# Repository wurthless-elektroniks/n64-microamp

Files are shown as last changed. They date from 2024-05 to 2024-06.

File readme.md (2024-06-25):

# n64-microamp: Extremely cheap and janky Nintendo 64 RGB amp mod

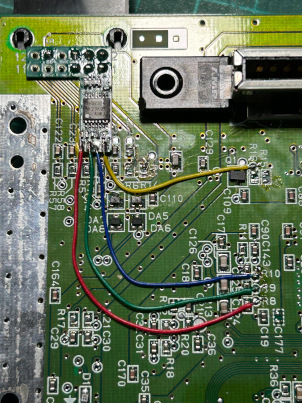
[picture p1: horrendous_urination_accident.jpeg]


Another exercise in extreme cost-downing. This time, it's an attempt to make the most minimalist yet still functional Nintendo 64 RGB amp.
This is accomplished in only eight tiny annoying-to-solder parts.

Circuit is entirely analog so you only get the Gerbers.

## Schematic

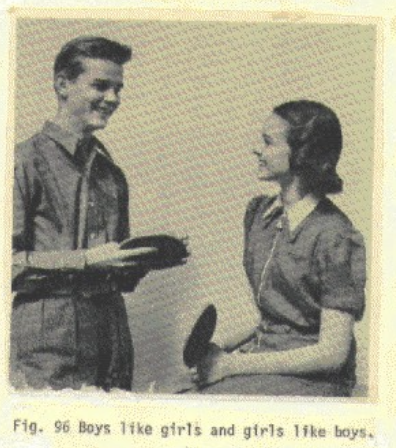
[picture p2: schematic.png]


Virtually the same as [Tzorri Mahm's board](https://github.com/TzorriMahm/N64_RGB_Amp), but with the following differences:

- The 47pF caps on the output lines have been removed. The THS7374 datasheet says these are there to prevent "ringing" interference,
  but they are not necessary for proper functionality.
- No ferrite bead on the power supply line.
- No power stabilization caps except for the one required by the THS7374.
- No lowpass filter enable pad. Sorry to all five people who use that feature.
- 0603 components have been changed to smaller and cheaper 0403s where safe to do so.
- 75 ohm current limiting resistors on the RGB outputs are now grouped together into a single 1206 resistor array.
- As a result of a lot of things being left off the board, the board has a somewhat smaller footprint, but is slightly longer.

## Installation

See readmes in Gerber directories for BoM and component placement information.

The four solderpoints at the end of the board are, in this order: R, G, B, CSYNC.

**On NUS-CPU-01 through NUS-CPU-03 boards**, the CSYNC pin on the multi-out will be driven by the N64. If you'd prefer to have the
amp board drive it, you need to remove these components: R1 R14 R15 R16 C22. If those components are not populated, then the
board has no CSYNC and you will need to install the CSYNC wire.

**On NUS-CPU-04 boards**, the components that normally drive CSYNC will not be on the board.

For the aforementioned boards, installation requires three or four wires:
- R -> R8
- G -> R9
- B -> R10
- If CSYNC needed, CSYNC -> R16

**NUS-CPU-05 through NUS-CPU-09 boards need a separate DAC to work with this mod.** Nintendo integrated NTSC video encoding onto a
single chip (AVDC-NUS and MAV-NUS) so there are no more analog RGB outputs. You will either need to use an external DAC or try
a different mod (Tim Worthington's N64RGB or [some shitty version of it](https://github.com/wurthless-elektroniks/rugby64)) to get RGB out of those systems.

**It's recommended, but not required, to put insulating material under the PCB before you solder it in.**

After installation, test everything and make sure it works. If you get RGB output, hooray for you. If not, something is wrong.

It's very important to check the temperature of the THS7374 amp when the circuit is running. If it's blistering hot, then there's
a short circuit on one of the outputs, most likely the CSYNC pin. Remedy this issue immediately to limit damage to the amp (and your N64).

## License

Public domain

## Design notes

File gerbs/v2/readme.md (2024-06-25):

# n64 microamp v2

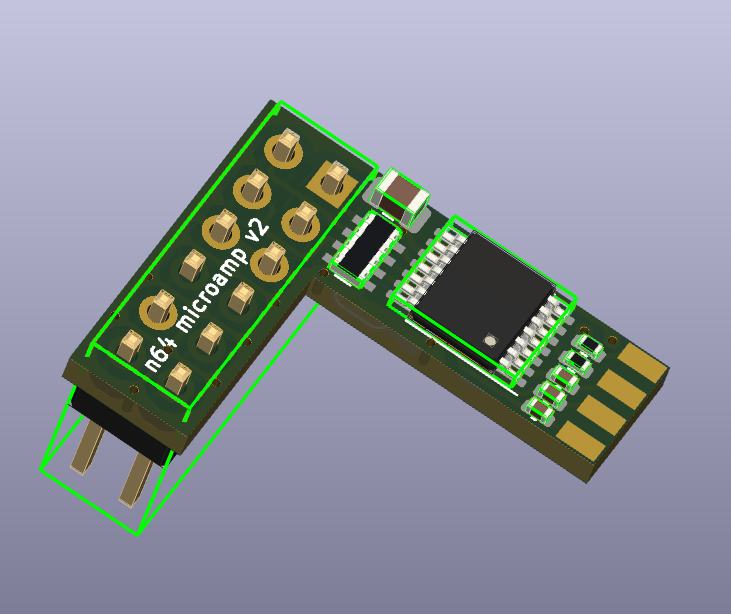
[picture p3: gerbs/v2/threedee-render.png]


First production-ready version, if you want to call it that. Cost per unit is easily below $5 a piece even after factoring in labor, shipping and customs charges.

## Changes from v1

- Smoothing cap is now a 10uF 0802
- Jumper on bottom side of PCB can be cut to prevent the amp from driving CSYNC if necessary

## Known issues

- I'm still waiting on the PCBs, but this is a design that I'm confident should work.
- I still haven't tested the CSYNC output as I only have a sync-on-luma SCART cable.

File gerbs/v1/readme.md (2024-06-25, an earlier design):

# Where Shit Goes

If you really want to assemble this:

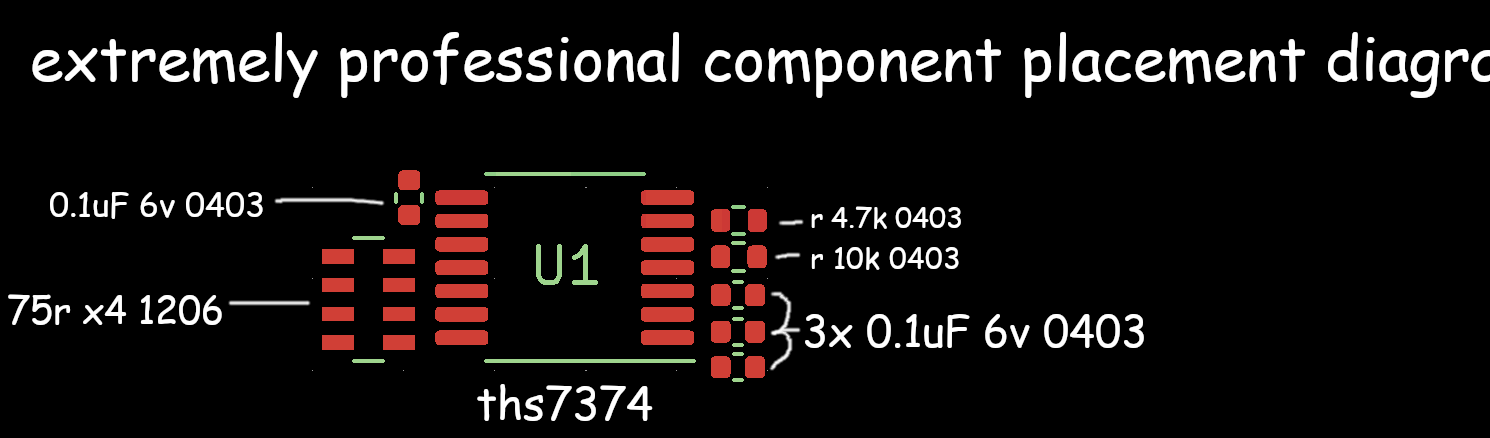
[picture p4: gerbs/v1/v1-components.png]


## Known issues

* The 0.1uF 0403 capacitor really pushes the jank factor of this design into the stratosphere. I have no idea
  how long this will hold up long term.
* I haven't tested the CSYNC output because the SCART cable I use is sync-on-composite. It is identical to Tsorri Mahm's
  implementation, so it *should* work. (Doesn't mean it will.)

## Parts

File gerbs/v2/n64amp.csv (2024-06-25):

Item | Qty | Reference(s) | Value | LibPart | Footprint | Datasheet | DNP | LCSC
1 | 3 | C1, C2, C3 | 0.1uF | Device:C | Capacitor_SMD:C_0402_1005Metric | ~ |  | C141382
2 | 1 | C4 | 10uF | Device:C | Capacitor_SMD:C_0805_2012Metric | ~ |  | C396721
3 | 1 | J1 | Conn_02x06_Odd_Even | Connector_Generic:Conn_02x06_Odd_Even | Connector_PinHeader_2.54mm:PinHeader_2x06_P2.54mm_Vertical | ~
4 | 1 | JP1 | Jumper_2_Bridged | Jumper:Jumper_2_Bridged | Jumper:SolderJumper-2_P1.3mm_Bridged_RoundedPad1.0x1.5mm | ~
5 | 1 | R1 | 4700 | Device:R | Resistor_SMD:R_0402_1005Metric | ~ |  | C208892
6 | 1 | R2 | 10000 | Device:R | Resistor_SMD:R_0402_1005Metric | ~ |  | C269674
7 | 1 | RN1 | 4x75R | Device:R_Pack04 | Resistor_SMD:R_Array_Concave_4x0603 | ~ |  | C606219
8 | 4 | TP1, TP2, TP3, TP4 | TestPoint | Connector:TestPoint | TestPoint:TestPoint_Pad_1.0x1.0mm | ~
9 | 1 | U1 | THS7374 | Amplifier_Video:THS7374 | Package_SO:TSSOP-14_4.4x5mm_P0.65mm | https://www.ti.com/lit/ds/symlink/ths7374.pdf |  | C2652746

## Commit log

2024-05-26 dislocating neck to self-fellate
    [n64amp-B_Cu.gbr, n64amp-B_Mask.gbr, n64amp-B_Paste.gbr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]
2024-06-25 vee 2: a whole second vee
    [n64amp-B_Cu.gbr, n64amp-B_Mask.gbr, n64amp-B_Paste.gbr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]
